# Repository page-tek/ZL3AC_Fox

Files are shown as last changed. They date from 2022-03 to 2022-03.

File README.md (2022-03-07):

# ZL3AC Fox
STM32 based ham radio direction finding transmitter

This project is a work in progress. There is no guarantee that the code or PCB is full functional at any time.

## PCB schematic and layout
The schematic and layout were produced with Kicad version 5, they have since been saved with Kicad version 6

## Software
The software has been developed in the Arduino IDE environment, using the STM32 Boards Manager addon.

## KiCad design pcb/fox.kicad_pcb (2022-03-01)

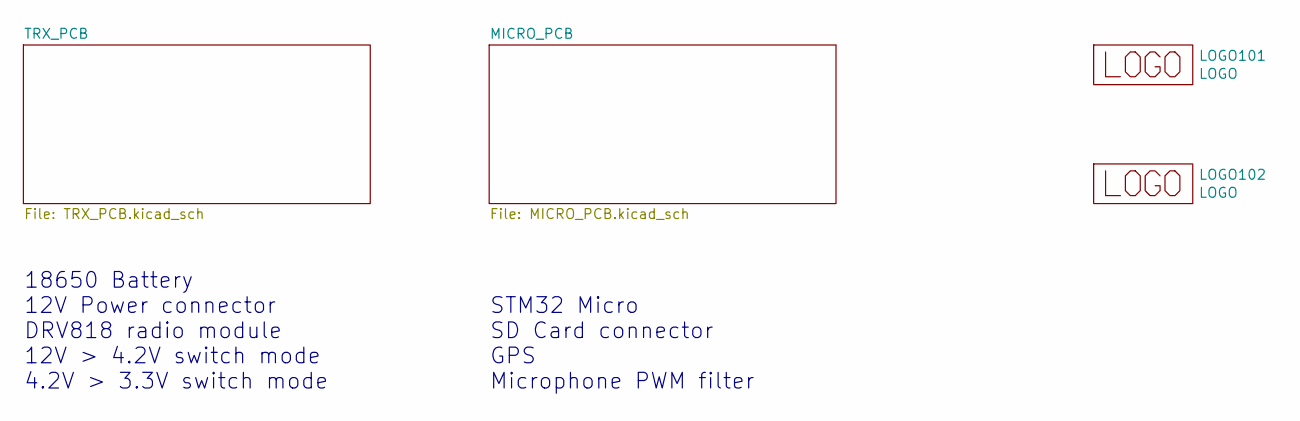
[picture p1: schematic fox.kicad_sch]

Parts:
LOGO101: LOGO; logo_12.5mm
LOGO102: LOGO; page-tek_25mm

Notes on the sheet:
18650 Battery 12V Power connector DRV818 radio module 12V > 4.2V switch mode 4.2V > 3.3V switch mode
STM32 Micro SD Card connector GPS Microphone PWM filter

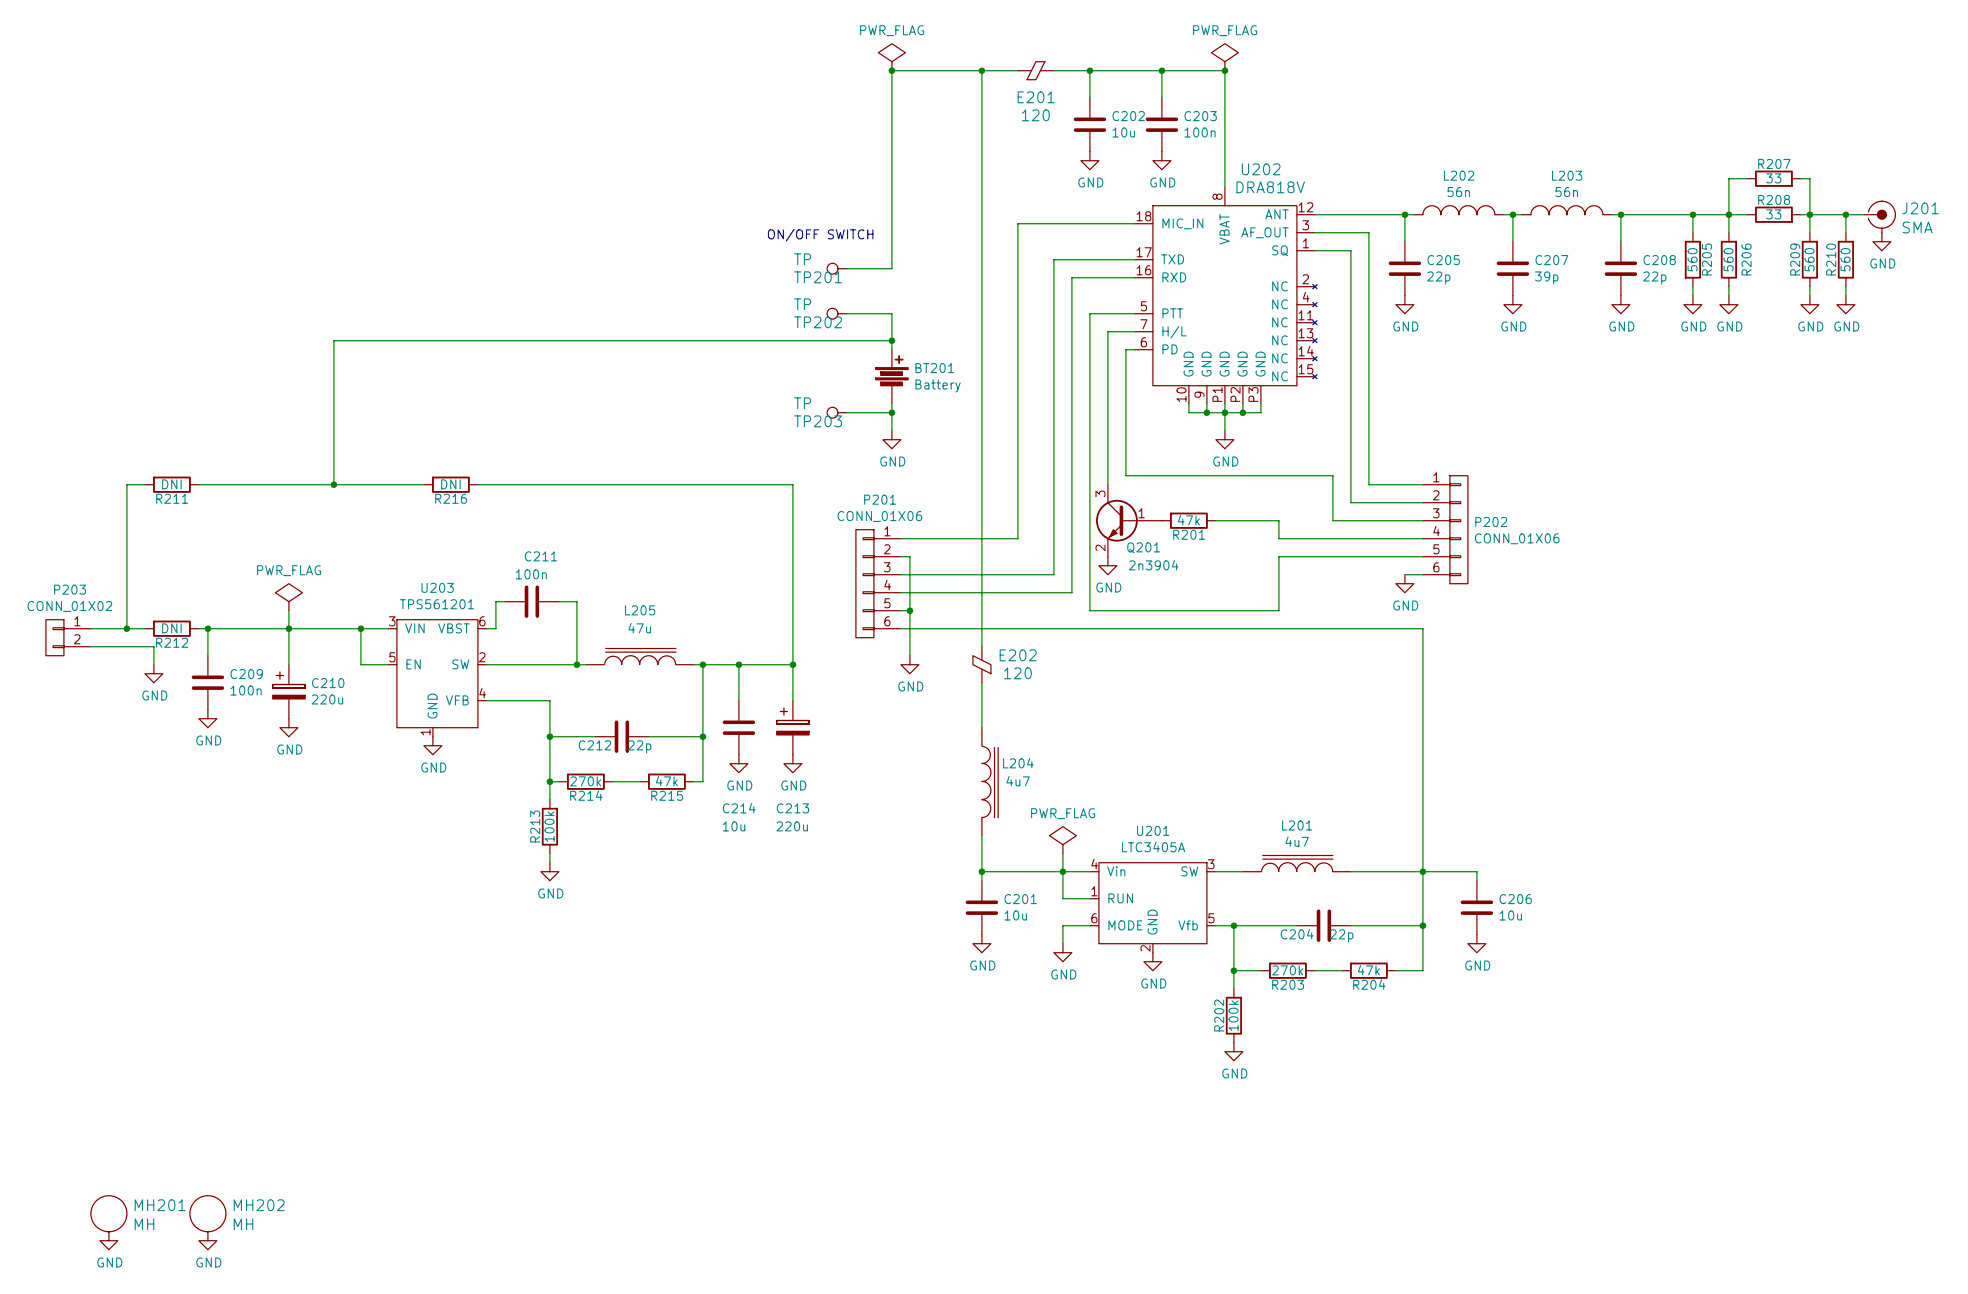
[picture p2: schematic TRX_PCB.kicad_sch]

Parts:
BT201: Battery; 1043-18650
C201, C202, C206, C214: 10u; CAPC160X80X90L35N-0603
C203, C209, C211: 100n; CAPC160X80X90L35N-0603
C204, C205, C208, C212: 22p; CAPC160X80X90L35N-0603
C207: 39p; CAPC160X80X90L35N-0603
C210, C213: 220u; CAPAE830X1030L290X95N
E201, E202: 120; RESC160X80X55L30N-0603
J201: SMA; sma_90_r300.124.403
L201, L204: 4u7; Coilcraft_XAL4030
L202, L203: 56n; Coilcraft_1812SMS
L205: 47u; Wurth_LQS_6045_ind
MH201, MH202: MH; MTGP600H320V6H60
P201, P202: CONN_01X06; HDRV6W64P254_6X1_1524X254H860
P203: CONN_01X02; JST-S2B-PH-SM4-TB
Q201: 2n3904; SOT23-3P95_237X112L40X40N-SOT23
R201, R204, R215: 47k; RESC160X80X55L30N-0603
R202, R213: 100k; RESC160X80X55L30N-0603
R203, R214: 270k; RESC160X80X55L30N-0603
R205, R206, R209, R210: 560; RESC200X125X60L35N-0805
R207, R208: 33; RESC200X125X60L35N-0805
R211, R212, R216: DNI; RESC160X80X55L30N-0603
TP201, TP202, TP203: TP; TP-SQ-2mm
U201: LTC3405A; SOT23-6P95_280X145L45X40N
U202: DRA818V; DRA818
U203: TPS561201; SOT23-6P65_210X110L36X22N-SOT323-6

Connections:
GND: BT201.2, C201.2, C202.2, C203.2, C205.2, C206.2, C207.2, C208.2, C209.2, C210.2, C213.2, C214.2, J201.2 (GND), MH201.1, MH202.1, P201.2, P201.5, P202.6, P203.2, Q201.2 (E), R202.1, R205.2, R206.1, R209.1, R210.1, R213.1, TP203.1, U201.2 (GND), U201.6 (MODE), U202.9 (GND), U202.10 (GND), U202.P1 (GND), U202.P2 (GND), U202.P3 (GND), U203.1 (GND); also elsewhere on the board
unnamed: BT201.1, R211.1, R216.2, TP202.1
unnamed: C201.1, L204.2, U201.1 (RUN), U201.4 (Vin)
unnamed: C202.1, C203.1, E201.2, U202.8 (VBAT)
unnamed: C204.1, C206.1, L201.2, P201.6, R204.1
unnamed: C204.2, R202.2, R203.2, U201.5 (Vfb)
unnamed: C205.1, L202.1, U202.12 (ANT)
unnamed: C207.1, L202.2, L203.1
unnamed: C208.1, L203.2, R205.1, R206.2, R207.1, R208.1
unnamed: C209.1, C210.1, R212.1, U203.3 (VIN), U203.5 (EN)
unnamed: C211.1, L205.1, U203.2 (SW)
unnamed: C211.2, U203.6 (VBST)
unnamed: C212.1, C213.1, C214.1, L205.2, R215.1, R216.1
unnamed: C212.2, R213.2, R214.2, U203.4 (VFB)
unnamed: E201.1, E202.1, TP201.1
unnamed: E202.2, L204.1
unnamed: J201.1 (RF), R207.2, R208.2, R209.2, R210.2
unnamed: L201.1, U201.3 (SW)
unnamed: P201.1, U202.18 (MIC_IN)
unnamed: P201.3, U202.17 (TXD)
unnamed: P201.4, U202.16 (RXD)
unnamed: P202.1, U202.3 (AF_OUT)
unnamed: P202.2, U202.1 (SQ)
unnamed: P202.3, U202.6 (PD)
unnamed: P202.4, R201.1
unnamed: P202.5, U202.5 (PTT)
unnamed: P203.1, R211.2, R212.2
unnamed: Q201.1 (B), R201.2
unnamed: Q201.3 (C), U202.7 (H/L)
unnamed: R203.1, R204.2
unnamed: R214.1, R215.2

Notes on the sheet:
ON/OFF SWITCH

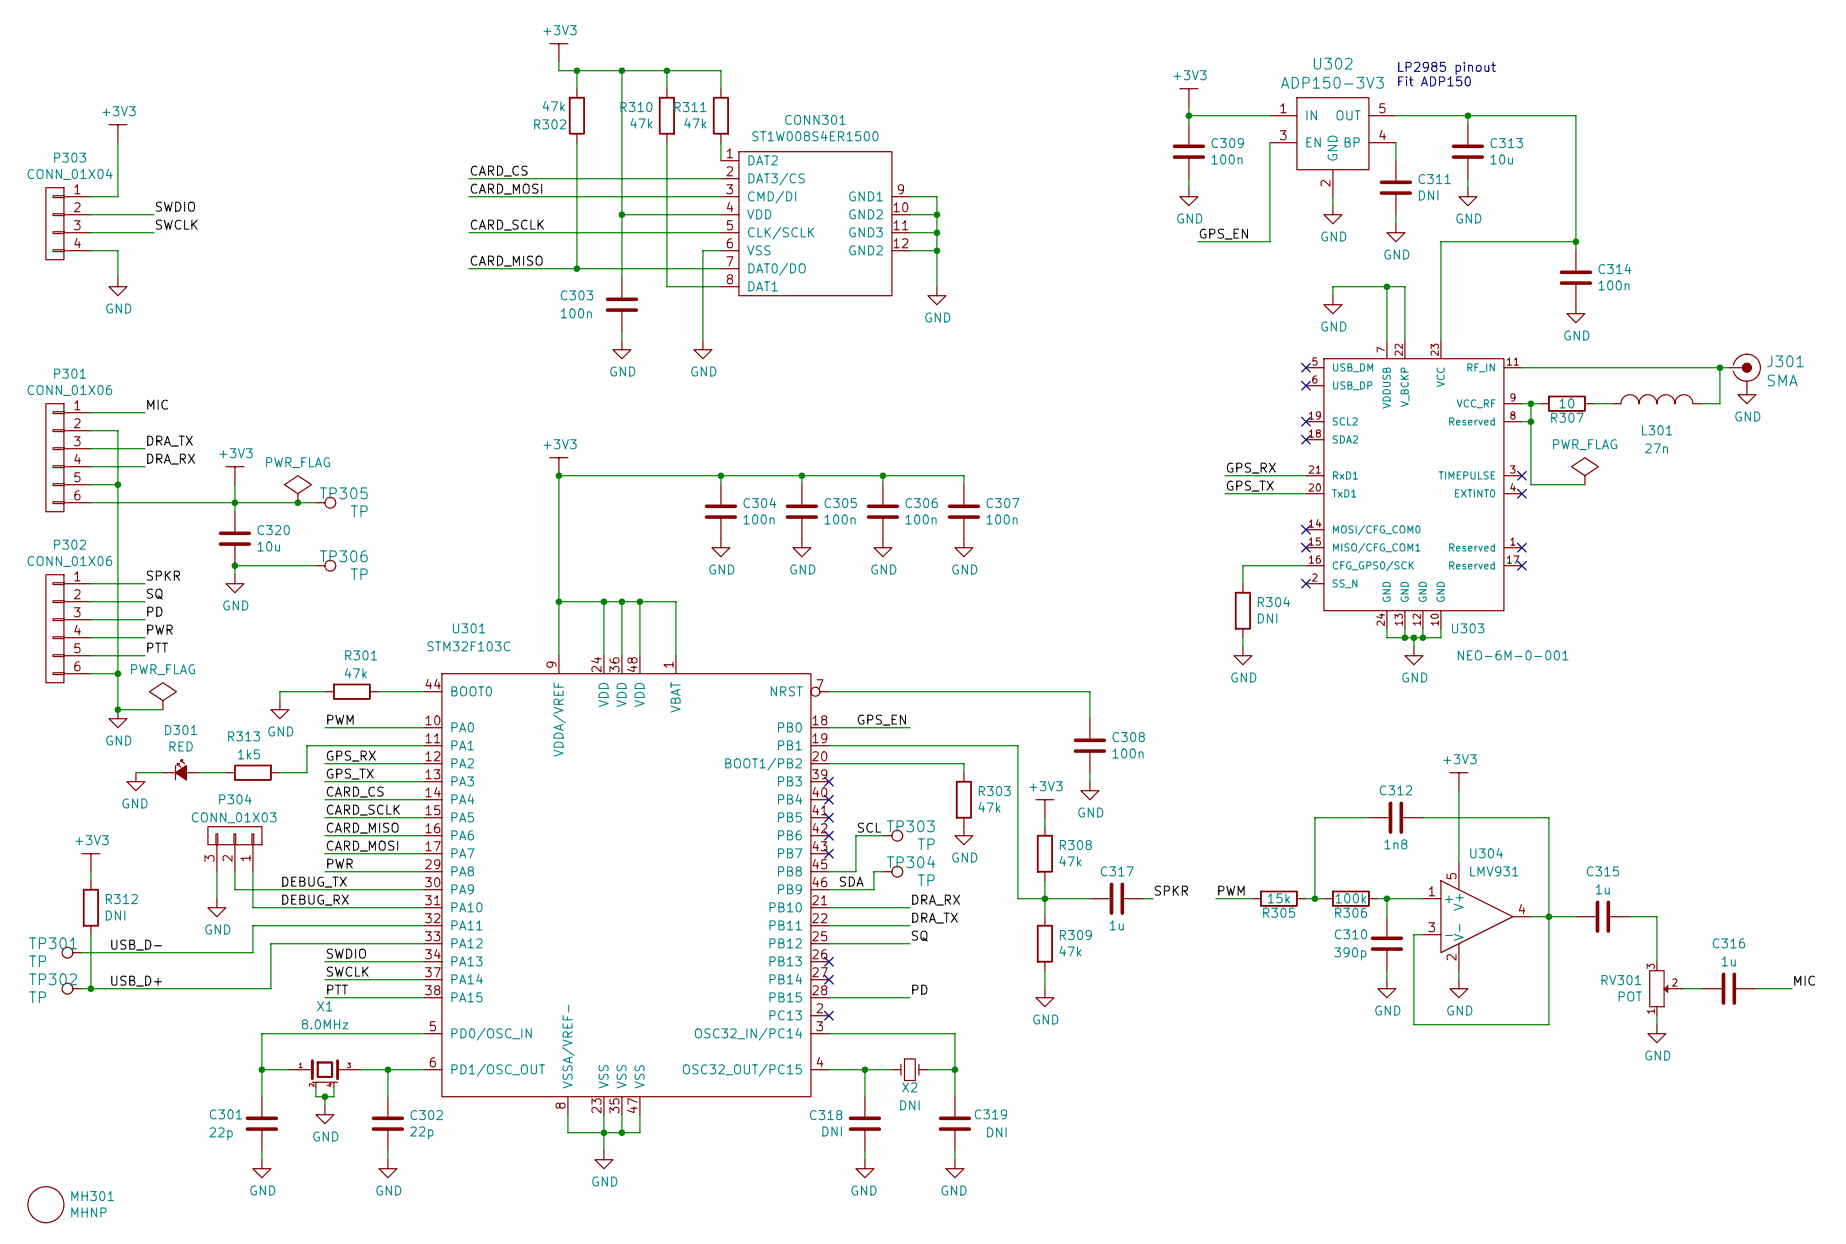
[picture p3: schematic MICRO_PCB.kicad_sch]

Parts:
C301, C302: 22p; CAPC160X80X90L35N-0603
C303, C304, C305, C306, C307, C308, C309, C314: 100n; CAPC160X80X90L35N-0603
C310: 390p; CAPC160X80X90L35N-0603
C311, C318, C319: DNI; CAPC160X80X90L35N-0603
C312: 1n8; CAPC160X80X90L35N-0603
C313, C320: 10u; CAPC160X80X90L35N-0603
C315, C316, C317: 1u; CAPC160X80X90L35N-0603
CONN301: ST1W008S4ER1500; JAE_ST1W008S4ER1500
D301: RED; LEDC200X125X90L40N-0805
J301: SMA; MOLEX-0734152063-MCX-SMD
L301: 27n; INDC180X76X102L33N-CC0603
MH301: MHNP; MTGNP500H300Z400
P301, P302: CONN_01X06; HDRV6W64P254_6X1_1524X254H860
P303: CONN_01X04; HDRV4W64P254_4X1_1016X254H860-alt2
P304: CONN_01X03; HDRV3W64P254_3X1_762X254H860
R301, R302, R303, R308, R309, R310, R311: 47k; RESC160X80X55L30N-0603
R304, R312: DNI; RESC160X80X55L30N-0603
R305: 15k; RESC160X80X55L30N-0603
R306: 100k; RESC160X80X55L30N-0603
R307: 10; RESC160X80X55L30N-0603
R313: 1k5; RESC160X80X55L30N-0603
RV301: POT; Bourns_TC33
TP301, TP302, TP303, TP304, TP305, TP306: TP; TP-1.5mm
U301: STM32F103C; QFP48P50_900X900X120L60X22N-TQFP48
U302: ADP150-3V3; SOT23-5P95_280X145L45X40N
U303: NEO-6M-0-001; ublox-NEO-6
U304: LMV931; SOT23-5P65_210X110L36X22N-SOT323-5
X1: 8.0MHz; XTAL500X320X130L90X120NN
X2: DNI; XTAL320X150X180L100

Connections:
+3V3: C303.1, C304.1, C305.1, C306.1, C307.1, C309.1, C320.1, CONN301.4 (VDD), P301.6, P303.1, R302.2, R308.1, R310.1, R311.1, R312.1, TP305.1, U301.1 (VBAT), U301.9 (VDDA/VREF), U301.24 (VDD), U301.36 (VDD), U301.48 (VDD), U302.1 (IN), U304.5 (V+)
/MICRO_PCB/CARD_CS: CONN301.2 (DAT3/CS), U301.14 (PA4)
/MICRO_PCB/CARD_MISO: CONN301.7 (DAT0/DO), R302.1, U301.16 (PA6)
/MICRO_PCB/CARD_MOSI: CONN301.3 (CMD/DI), U301.17 (PA7)
/MICRO_PCB/CARD_SCLK: CONN301.5 (CLK/SCLK), U301.15 (PA5)
/MICRO_PCB/DEBUG_RX: P304.1, U301.31 (PA10)
/MICRO_PCB/DEBUG_TX: P304.2, U301.30 (PA9)
/MICRO_PCB/DRA_RX: P301.4, U301.21 (PB10)
/MICRO_PCB/DRA_TX: P301.3, U301.22 (PB11)
/MICRO_PCB/GPS_EN: U301.18 (PB0), U302.3 (EN)
/MICRO_PCB/GPS_RX: U301.12 (PA2), U303.21 (RxD1)
/MICRO_PCB/GPS_TX: U301.13 (PA3), U303.20 (TxD1)
/MICRO_PCB/MIC: C316.1, P301.1
/MICRO_PCB/PD: P302.3, U301.28 (PB15)
/MICRO_PCB/PTT: P302.5, U301.38 (PA15)
/MICRO_PCB/PWM: R305.2, U301.10 (PA0)
/MICRO_PCB/PWR: P302.4, U301.29 (PA8)
/MICRO_PCB/SCL: TP303.1, U301.45 (PB8)
/MICRO_PCB/SDA: TP304.1, U301.46 (PB9)
/MICRO_PCB/SPKR: C317.1, P302.1
/MICRO_PCB/SQ: P302.2, U301.25 (PB12)
/MICRO_PCB/SWCLK: P303.3, U301.37 (PA14)
/MICRO_PCB/SWDIO: P303.2, U301.34 (PA13)
/MICRO_PCB/USB_D+: R312.2, TP302.1, U301.33 (PA12)
/MICRO_PCB/USB_D-: TP301.1, U301.32 (PA11)
GND: C301.2, C302.2, C303.2, C304.2, C305.2, C306.2, C307.2, C308.2, C309.2, C310.2, C311.2, C313.2, C314.2, C318.2, C319.2, C320.2, CONN301.6 (VSS), CONN301.9 (GND1), CONN301.10 (GND2), CONN301.11 (GND3), CONN301.12 (GND2), D301.1 (K), J301.2 (GND), P301.2, P301.5, P302.6, P303.4, P304.3, R301.2, R303.2, R304.2, R309.2, RV301.1, TP306.1, U301.8 (VSSA/VREF-), U301.23 (VSS), U301.35 (VSS), U301.47 (VSS), U302.2 (GND), U303.7 (VDDUSB), U303.10 (GND), U303.12 (GND), U303.13 (GND), U303.22 (V_BCKP), U303.24 (GND), U304.2 (V-), X1.2 (GND), X1.4 (GND); also elsewhere on the board
unnamed: C301.1, U301.5 (PD0/OSC_IN), X1.1
unnamed: C302.1, U301.6 (PD1/OSC_OUT), X1.3
unnamed: C308.1, U301.7 (NRST)
unnamed: C310.1, R306.1, U304.1 (+)
unnamed: C311.1, U302.4 (BP)
unnamed: C312.1, C315.2, U304.3 (-), U304.4
unnamed: C312.2, R305.1, R306.2
unnamed: C313.1, C314.1, U302.5 (OUT), U303.23 (VCC)
unnamed: C315.1, RV301.3
unnamed: C316.2, RV301.2
unnamed: C317.2, R308.2, R309.1, U301.19 (PB1)
unnamed: C318.1, U301.4 (OSC32_OUT/PC15), X2.1
unnamed: C319.1, U301.3 (OSC32_IN/PC14), X2.2
unnamed: CONN301.1 (DAT2), R311.2
unnamed: CONN301.8 (DAT1), R310.2
unnamed: D301.2 (A), R313.1
unnamed: J301.1 (RF), L301.2, U303.11 (RF_IN)
unnamed: L301.1, R307.1
unnamed: R301.1, U301.44 (BOOT0)
unnamed: R303.1, U301.20 (BOOT1/PB2)
unnamed: R304.1, U303.16 (CFG_GPS0/SCK)
unnamed: R307.2, U303.8 (Reserved), U303.9 (VCC_RF)
unnamed: R313.2, U301.11 (PA1)

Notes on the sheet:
LP2985 pinout Fit ADP150

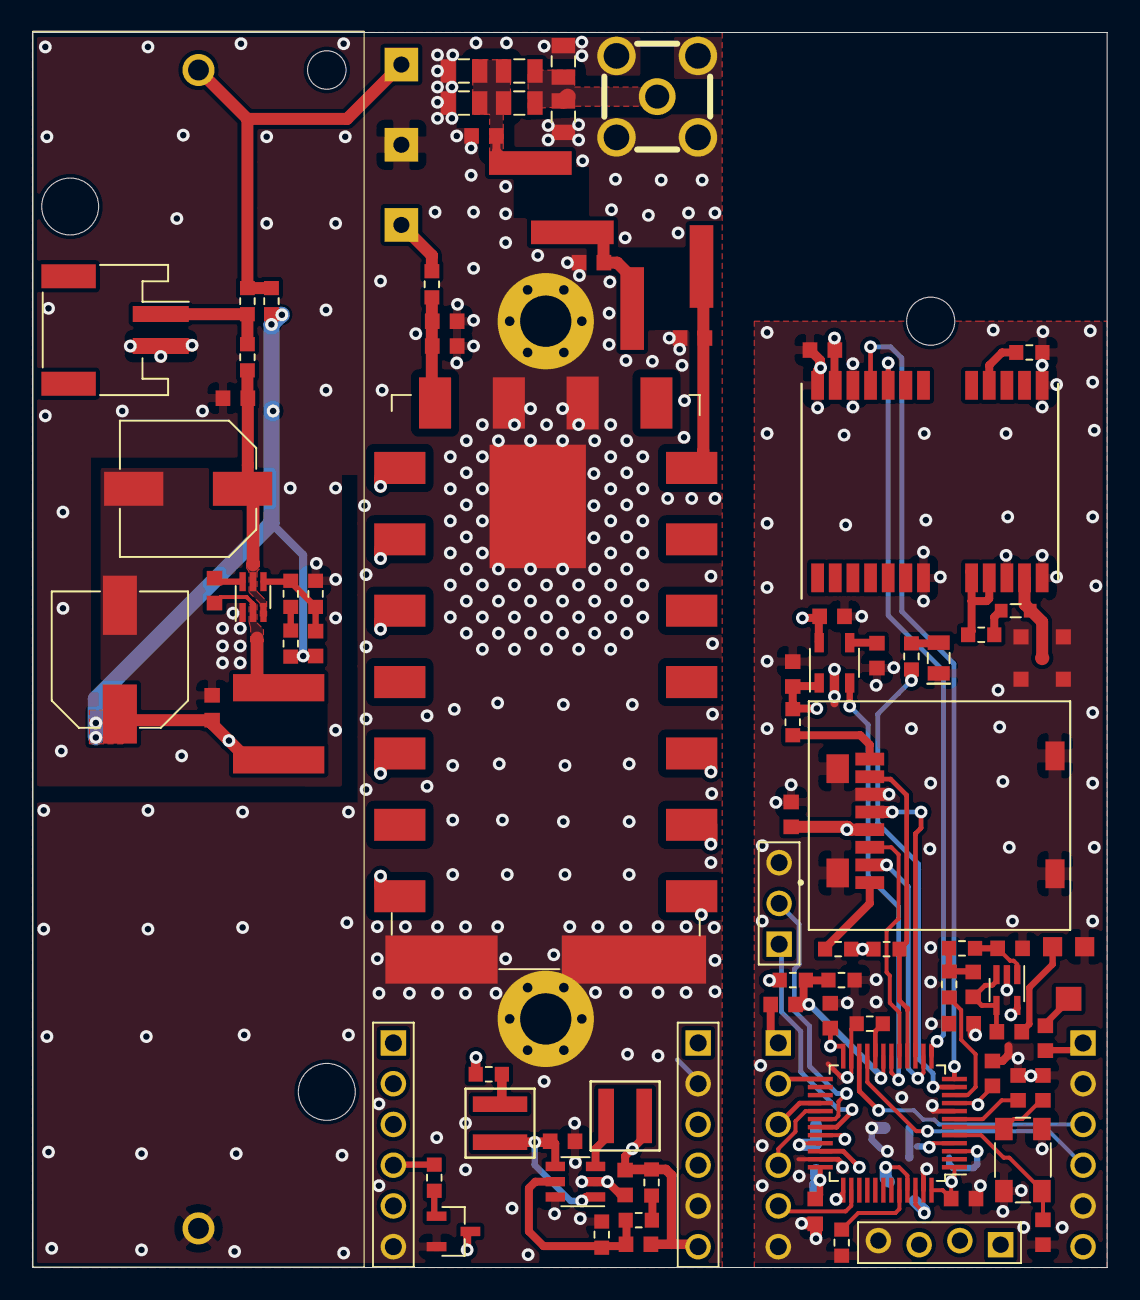
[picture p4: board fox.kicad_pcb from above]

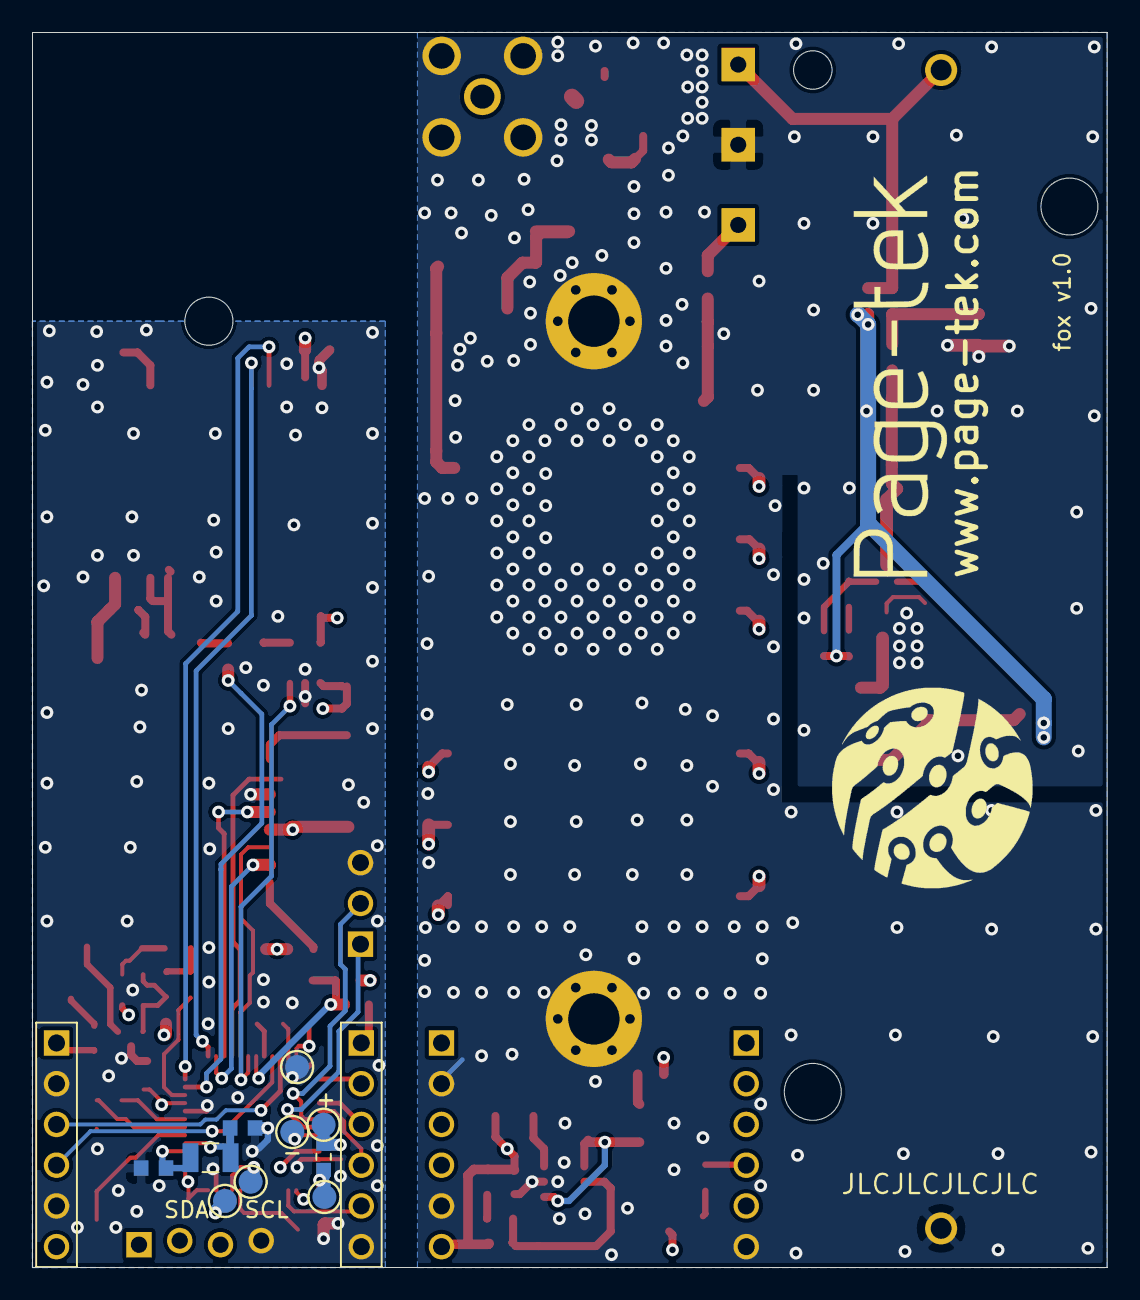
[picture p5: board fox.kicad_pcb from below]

Board: 4 copper layers, 67.0 x 77.0 mm, 108 parts (14 on the bottom side), 79 nets.

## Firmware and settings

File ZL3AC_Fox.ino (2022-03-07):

// ZL3AC FOX
// ---------
//
// Compile with the following Arduino IDE settings:
//
// Board: Generic STM32F1 series
// Board Part Number: Blue Pill F103C8
// U(S)ART support: Enable (generic 'Serial')
// USB Support: None


#include <TinyGPS.h>
#include <Timezone.h>   // https://github.com/JChristensen/Timezone
#include <TimeLib.h>    // https://github.com/PaulStoffregen/Time
#include <SPI.h>
#include <SdFat.h>
#include "stdlib.h" //for atoi

// Setup audio file playback variables
// Chip select PA4, shared SPI, 18 MHz, port 1.
#define SD1_CONFIG SdSpiConfig(PA4, DEDICATED_SPI, SD_SCK_MHZ(18), &SPI)
SdFat sd;
File fileHandle;
#define BUFFERSIZE 2048

//This is the amount of data to be fetched from the SD card for each read.
#define BUFFERSIZE 2048
char buffer0[BUFFERSIZE], buffer1[BUFFERSIZE];  //Two cycling buffers which contain the WAV data.

volatile uint8_t note=0;    //Holds the current voltage value to be sent.
uint8_t play_buffer=0;         //Keeps track of which buffer is currently being used
uint8_t new_buffer_ready=0;      //Flag used by 'Loop' code to tell the Interrupt that new data is ready in the buffer.
volatile uint16_t byte_count=0; //Keeps track of the number of bytes read from the current buffer.
volatile uint8_t need_new_data=0;    //Flag used by Interrupt to tell 'Loop' code that a buffer is empty and needs to be refilled.
volatile uint8_t playing=0;  //Flag to see when we need to finish playing a file.

TIM_TypeDef *PWMInstance = TIM2; //timer for PWM frequency
HardwareTimer *PWMTimer = new HardwareTimer(PWMInstance);
uint32_t PWMchannel = STM_PIN_CHANNEL(pinmap_function(digitalPinToPinName(PA0), PinMap_PWM));

TIM_TypeDef *SampleInstance = TIM3; //timer for sample frequency
HardwareTimer *SampleTimer = new HardwareTimer(SampleInstance);

/* GPS setup, change TinyGPS to recognise GNRMC */
TinyGPS gps;
HardwareSerial SerialGPS(USART2);
#define GPSEnable PB0

/* New Zealand Time Zone setup*/
TimeChangeRule nzSTD = {"NZST", First, Sun, Apr, 3, 720};   // UTC + 12 hours
TimeChangeRule nzDST = {"NZDT", Last, Sun, Sep, 2, 780};    // UTC + 13 hours
Timezone nz(nzDST, nzSTD);
time_t startTime;
uint32_t txInterval = 0;

HardwareSerial SerialRadio(USART3);
#define lowPower PA8
#define PTT PA15
#define powerDown PB15
#define sqIn PB12
char freqBuffer[12];

#define LED PA1

inline void enableGPS(uint8_t en) { digitalWrite(GPSEnable, en); }

inline void disableRadio() { 
  digitalWrite(powerDown, LOW); 
  digitalWrite(PTT, HIGH); // now open drain output
  digitalWrite(lowPower, LOW);
  //SerialRadio.end();  // seems to disable all serial ports
  //Serial.begin(115200); // so start up the ones we need
  //SerialGPS.begin(9600);
  pinMode(PB10, INPUT);
}

inline void enableRadio() { 
  digitalWrite(PTT, HIGH); 
  digitalWrite(powerDown, HIGH);
  digitalWrite(lowPower, HIGH);
  SerialRadio.begin(9600);
}

inline void transmit(uint8_t tx) { digitalWrite(PTT, tx?LOW:HIGH); }

inline void txLowPower(uint8_t power) { digitalWrite(lowPower, power?HIGH:LOW);}

inline void LEDon(uint8_t led) { digitalWrite(LED, led); }

void flashError(uint8_t flashes)
{
  uint8_t n=0;

  while(1) {
    for(n=0;n<flashes;n++){
      LEDon(true);
      delay(150);
      LEDon(false);
      delay(300);
    }
    delay(1000);
  }
}

// This timer interrupt will run every 1/48000Hz. 
// This is frequency of the WAV files that will be played by this sketch.
void UpdateAudioSample(void)
{
  //Check to see if we've read all of the data in the current buffer
  if(byte_count==BUFFERSIZE)
  {
    need_new_data=1;  //Set a flag to tell the 'loop' code to refill the current buffer.
    byte_count=0;   //Reset the count
    //Check to see if new data exists in the alternate buffer
    if(new_buffer_ready==1) {
      //If new data is available, reassign the play buffer.
      if(play_buffer==0)play_buffer=1;
      else play_buffer=0;
    } else {
      //If no new data is available then wait for it!
      Serial.print("UF");
      return;
    }
  }
  
  //Find out which buffer is being used, and get data from it.
  if(play_buffer==0) {
      PWMTimer->setCaptureCompare(PWMchannel, buffer0[byte_count], RESOLUTION_8B_COMPARE_FORMAT);
  }
  else {
    PWMTimer->setCaptureCompare(PWMchannel, buffer1[byte_count], RESOLUTION_8B_COMPARE_FORMAT);
  }
  
  //Increase the byte_count since we've taken the current data.
  byte_count +=1;
}  

void printDateTime(time_t t)
{
    char buf[32];
    char m[4];    // temporary storage for month string (DateStrings.cpp uses shared buffer)
    strcpy(m, monthShortStr(month(t)));
    sprintf(buf, "%.2d:%.2d:%.2d %s %.2d %s %d",
        hour(t), minute(t), second(t), dayShortStr(weekday(t)), day(t), m, year(t));
    Serial1.println(buf);
}

void setup() {
  // Debug serial port
  Serial.begin(115200);
  Serial.println("****");
  // Radio serial port
  //SerialRadio.begin(9600); run when module enabled
 
  // Set default pin states
  pinMode(GPSEnable, OUTPUT);
  enableGPS(false);
  
  pinMode(powerDown, OUTPUT);
  pinMode(PTT, OUTPUT_OPEN_DRAIN);
  pinMode(lowPower, OUTPUT);
  disableRadio();

  //power up LED notification
  pinMode(LED, OUTPUT);
  LEDon(true);
  delay(1000);
  LEDon(false);
  delay(500);
  LEDon(true);
  delay(1000);
  LEDon(false);
  delay(500);
  
  // Start the CD card
  if (!sd.begin(SD1_CONFIG)) {
    Serial.println("SD initialization failed!");
    flashError(1);
  }
  Serial.println("SD initialization done.");

  // Can we open the audio file
  Serial.print("Opening audio.wav...");
  // open the audio file. note that only one file can be open at a time,
  fileHandle = sd.open("audio.wav", FILE_READ);
  if (!fileHandle) {
    Serial.println("open audio.wav failed!");
    flashError(2);
  }
  Serial.println("audio.wav valid.");
  fileHandle.close();

  // Get the frequency
  fileHandle = sd.open("freq.txt", FILE_READ);
  if (!fileHandle) {
    Serial.println("open freq.txt failed!");
    flashError(3);
  }
  Serial.print("freq.txt opened....");

  fileHandle.read(freqBuffer, 8);
  fileHandle.close();
  freqBuffer[8] = 0;
  if ((freqBuffer[0] != '1') ||
      (freqBuffer[1] != '4') ||
      (freqBuffer[3] != '.'))  flashError(4);
  Serial.print("freq.txt parsed - ");
  Serial.println(freqBuffer);

  // Get start time
  fileHandle = sd.open("start.txt", FILE_READ);
  if (!fileHandle) {
    Serial.println("open start.txt failed!");
    flashError(4);
  }
  Serial.print("start.txt opened....");

  fileHandle.read(buffer0, 64);
  fileHandle.close();
  
  tmElements_t tm;
  tm.Year = atoi(buffer0) - 1970;
  tm.Month = atoi(buffer0+5);
  tm.Day = atoi(buffer0+8);
  tm.Hour = atoi(buffer0+11);
  tm.Minute = atoi(buffer0+14);
  tm.Second = atoi(buffer0+17);
  startTime = makeTime(tm);
  Serial.print("start.txt parsed - ");
  printDateTime(startTime);

  // see if tx time is in the past.
  Serial.print("Testing date....");
  enableGPS(true);
  SerialGPS.begin(9600);
  uint8_t dateInvalid = 1;
  while (dateInvalid) {
    while (SerialGPS.available()) {
      char gps_char = SerialGPS.read();
      if (gps_char == '$') Serial.print('.');
      if (gps.encode(gps_char)) { // process gps messages
        // when TinyGPS reports new data...
  
        tmElements_t tm;
        int year;
        gps.crack_datetime(&year, &tm.Month, &tm.Day, &tm.Hour, &tm.Minute, &tm.Second, NULL, NULL);
        tm.Year = year - 1970; 
        time_t time = makeTime(tm);
  
        time_t localTime = nz.toLocal(time);
        printDateTime(localTime);
        
        if (localTime > startTime) {
          Serial.println("date invalid.");
          flashError(8);
        } else {
          dateInvalid = 0;
          Serial.println("date valid");
        }
        
        }
    }
  }

  // Get tx interval time
  fileHandle = sd.open("interval.txt", FILE_READ);
  if (!fileHandle) {
    Serial.println("Open interval.txt failed!");
    flashError(4);
  }
  Serial.print("start.txt opened....");

  fileHandle.read(buffer0, 64);
  fileHandle.close();

  txInterval = atoi(buffer0);
  if (txInterval == 0) {
    Serial.println("Could not parse.");
    flashError(5);
  }
  if ( (txInterval < 15) || (txInterval > 300) ) {
    Serial.println("Number to large or small.");
  }
  Serial.print("interval.txt parsed - ");
  Serial.print(txInterval);
  Serial.println(" seconds");
  


  enableRadio();
  Serial.println("Radio enabled");
  delay(1000);

  // set parameters for DRA818V
  SerialRadio.print("AT+DMOSETGROUP=");         // begin message
  SerialRadio.print("1"); // bandwith in KHz ( 0= 12.5KHz or 1= 25KHz )
  SerialRadio.print(",");
  SerialRadio.print(freqBuffer);
  SerialRadio.print(",");
  SerialRadio.print(freqBuffer);
  SerialRadio.print(",");
  SerialRadio.print("0000"); // ctcss frequency ( 0000 - 0038 ); 0000 = "no CTCSS"
  SerialRadio.print(",");
  SerialRadio.print("0"); //squelch level 0 (0-8)
  SerialRadio.print(",");
  SerialRadio.println("0000"); // ctcss frequency ( 0000 - 0038 ); 0000 = "no CTCSS"
  
  long start = millis();
  do  {
    if (SerialRadio.available()) {
      Serial.write (SerialRadio.read());
    } 
  }while ( (millis() - start)  < 2000);

  Serial.println("Removing tail tone.");
  SerialRadio.println("AT+SETTAIL=0");
  start = millis();
  do  {
    if (SerialRadio.available()) {
      Serial.write (SerialRadio.read());
    } 
  }while ( (millis() - start)  < 2000);
  
  Serial.println("Radio programmed");

  fileHandle = sd.open("audio.wav", FILE_READ);
  if (!fileHandle) {
    flashError(5);
  }
  Serial.println("Audio file opened for playback.");
  delay(100);
  
  //Setup PWM timer
  PWMTimer->setPWM(PWMchannel, PA0, 192000, 50); // 384kHz Hertz, 50% dutycycle
  Serial.println("PWM timer setup.");
  delay(100);

  SampleTimer->setOverflow(48000, HERTZ_FORMAT); // 48kHz smaple rate
  SampleTimer->attachInterrupt(UpdateAudioSample);
  SampleTimer->pause();
  Serial.println("Sample timer setup.");
  delay(100);

  Serial.println("Reading header...");
  delay(100);
  //Read the header information. Alternate purpose is to get to the DATA offset of the file.
  fileHandle.read(buffer1, 44);
  Serial.println("Filling buffers...");
  delay(100);  
  //Set the initial play buffer, and grab the initial data from the SD card.
  play_buffer=0;
  fileHandle.read(buffer0, BUFFERSIZE);
  fileHandle.read(buffer1, BUFFERSIZE);
  new_buffer_ready=1;

  Serial.println("Starting Playback.");
  transmit(true);
  delay(1200); //module takes time to TX
  
  //Enable interrupts to start the wav playback.
  SampleTimer->resume();
  playing = 1;
  while(playing){
    if(need_new_data==1)  //need_new_data flag is set by ISR to indicate a buffer is empty and should be refilled
    {
      need_new_data=0;  //Clear the flag.
      if(play_buffer==0)  //play_buffer indicates which buffer is playing
      {
        //Get the next BUFFERSIZE bytes from the file.
        fileHandle.read(buffer1, BUFFERSIZE);
      }
      else
      {
        //Get the next BUFFERSIZE bytes from the file.
        fileHandle.read(buffer0, BUFFERSIZE);
      }
      new_buffer_ready=1; //new_buffer_ready flag tells the ISR that the buffer has been filled.
      
      //If file_read returns 0 or -1 file is over.
      if(!fileHandle.available())
      {
        playing = 0; //we have finished
        transmit(false);
        //PWMTimer->setCaptureCompare(PWMchannel, 50, PERCENT_COMPARE_FORMAT);
        PWMTimer->pause();
        SampleTimer->pause(); //Disable interrupts to stop playback.
        fileHandle.close();
        Serial.println("Finished playing.");
      }
    }
  }
  delay(100); //spit out serial before end()
  //disableRadio();
  
  
}


void loop() {
  char gps_char;
  
  while (SerialGPS.available()) {
    gps_char = SerialGPS.read();
    //Serial.print(gps_char);
    if (gps.encode(gps_char)) { // process gps messages
      // when TinyGPS reports new data...

      tmElements_t tm;
      int year;
      gps.crack_datetime(&year, &tm.Month, &tm.Day, &tm.Hour, &tm.Minute, &tm.Second, NULL, NULL);
      tm.Year = year - 1970; 
      time_t time = makeTime(tm);

      time_t localTime = nz.toLocal(time);
      printDateTime(localTime);
      
      if (localTime >= startTime) {
        fileHandle = sd.open("audio.wav", FILE_READ);
        if (!fileHandle) {
          flashError(5);
        }
        Serial.println("Audio file opened for playback.");
        delay(100);
        
        
        Serial.println("Reading header...");
        delay(100);
        //Read the header information. Alternate purpose is to get to the DATA offset of the file.
        fileHandle.read(buffer1, 44);
        Serial.println("Filling buffers...");
        delay(100);  
        //Set the initial play buffer, and grab the initial data from the SD card.
        play_buffer=0;
        fileHandle.read(buffer0, BUFFERSIZE);
        fileHandle.read(buffer1, BUFFERSIZE);
        new_buffer_ready=1;
      
        Serial.println("Starting Playback.");
        transmit(true);
        delay(1200); //module takes time to TX
        
        //Enable interrupts to start the wav playback.
        PWMTimer->resume();
        SampleTimer->resume();
        playing = 1;
        while(playing){
          if(need_new_data==1)  //need_new_data flag is set by ISR to indicate a buffer is empty and should be refilled
          {
            need_new_data=0;  //Clear the flag.
            if(play_buffer==0)  //play_buffer indicates which buffer is playing
            {
              //Get the next BUFFERSIZE bytes from the file.
              fileHandle.read(buffer1, BUFFERSIZE);
            }
            else
            {
              //Get the next BUFFERSIZE bytes from the file.
              fileHandle.read(buffer0, BUFFERSIZE);
            }
            new_buffer_ready=1; //new_buffer_ready flag tells the ISR that the buffer has been filled.
            
            //If file_read returns 0 or -1 file is over.
            if(!fileHandle.available())
            {
              playing = 0; //we have finished
              transmit(false);
              //PWMTimer->setCaptureCompare(PWMchannel, 50, PERCENT_COMPARE_FORMAT);
              PWMTimer->pause();
              SampleTimer->pause(); //Disable interrupts to stop playback.
              fileHandle.close();
              Serial.println("Finished playing.");
            }
          }
        }        



        startTime += txInterval;
      }
      
      }
  }
}
